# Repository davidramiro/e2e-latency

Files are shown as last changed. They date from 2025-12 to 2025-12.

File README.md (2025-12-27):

# m2p-latency

Get a rough estimate on mouse-to-photon (time until a mouse input triggers a screen change) system latency by attaching a phototransistor to your screen and measuring response time with an Arduino.

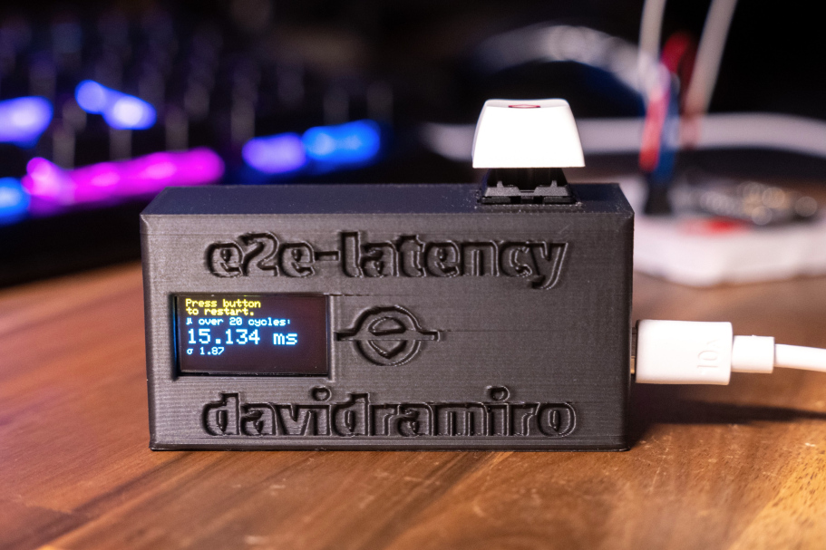
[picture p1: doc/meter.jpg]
Latency Meter


## BoM

- Arduino Pro Micro (ATmega32U4)
- SSD1306 I2C OLED screen
- TEMT6000 phototransistor
- Cherry MX switch

## Wiring

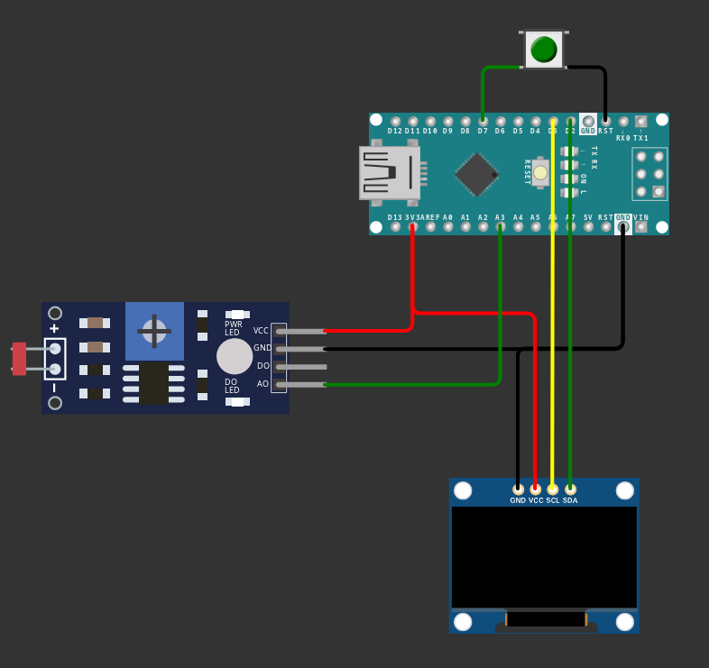
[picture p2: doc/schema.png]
Wiring


## Usage

- Set up a repeatable test scenario where a mouse click would cause a screen change (e.g. FPS game, mouse latency test at [testufo.com](https://testufo.com/flicker)
- Hold the photo transistor to the screen
- Connect USB
- Press button to start 20 measurements, wait for average to be reported on screen

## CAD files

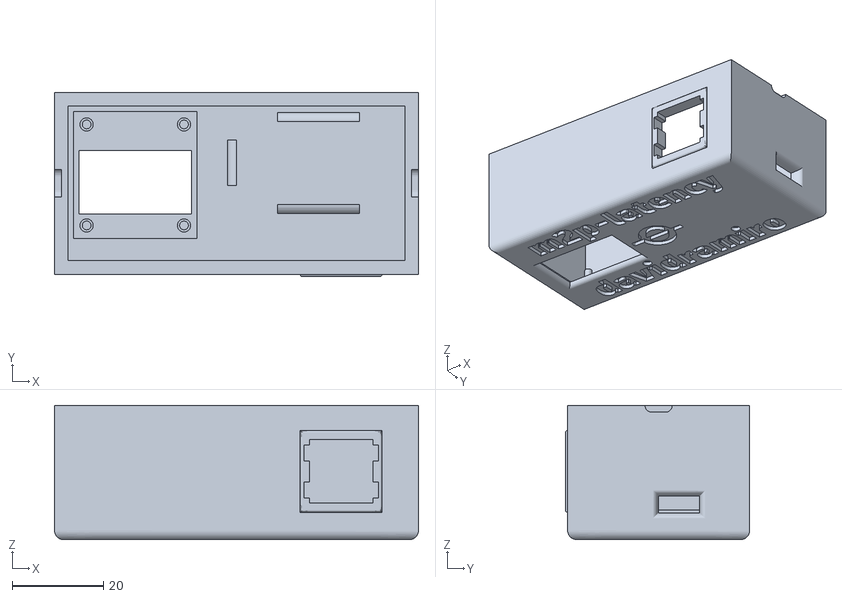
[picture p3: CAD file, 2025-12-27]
case/case.stl
80.0 x 40.5 x 29.5

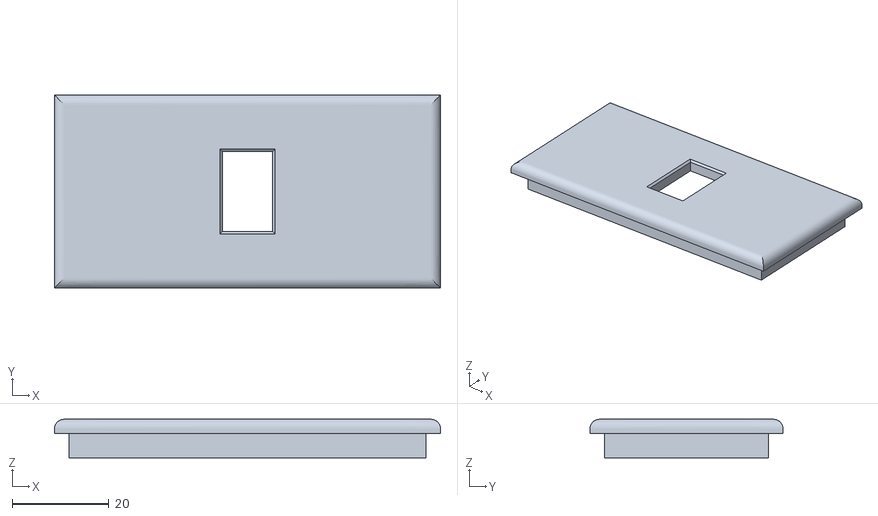
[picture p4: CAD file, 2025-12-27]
case/lid.stl
80.0 x 40.0 x 8.00

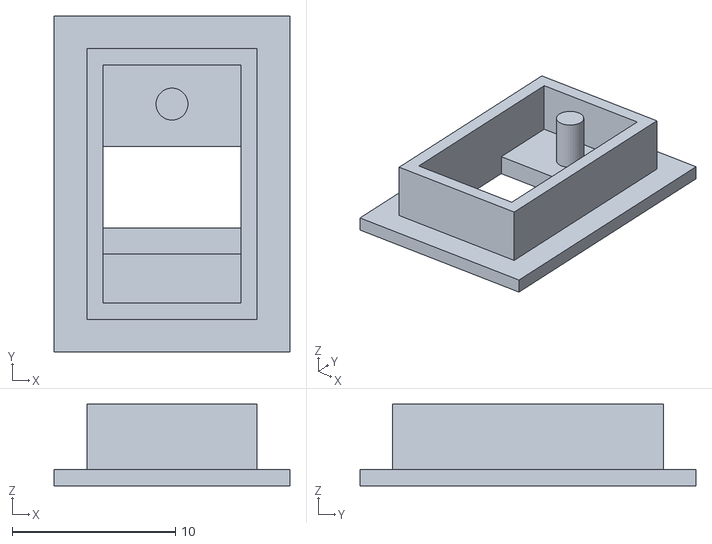
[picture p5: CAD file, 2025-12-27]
case/housing.stl
14.5 x 20.6 x 5.00

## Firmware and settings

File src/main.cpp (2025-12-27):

#include "main.h"

uint32_t latencies_us[NUM_CYCLES] = {0};
uint8_t cycle_index = 0;

volatile boolean startRequested = false;
volatile boolean restartRequested = false;
boolean running = false;

/// @brief Inits analog pin and mouse HID
void setup()
{
  initScreen();

  pinMode(BUTTON_PIN, INPUT_PULLUP);
  attachInterrupt(digitalPinToInterrupt(BUTTON_PIN), isr, FALLING);
}

/// @brief Measures brightness, waits for brightness change, saves latency. Shows an average after last cycle.
void loop()
{
  if (startRequested)
  {
    startRequested = false;
    restartRequested = false;
    Mouse.begin();

    while (cycle_index < NUM_CYCLES)
    {
      measure();

      if (restartRequested)
      {
        Mouse.release();
        cycle_index = 0;

        drawInterrupted();
        delay(1000);
        startRequested = false;
        restartRequested = false;
        running = false;
        drawStartupScreen();
        break;
      }
    }

    if (cycle_index == NUM_CYCLES)
    {

      double mean_ms = 0.0;
      double sd_ms = 0.0;
      computeStatsMs(&mean_ms, &sd_ms);
      printAverage(mean_ms, sd_ms);

      cycle_index = 0;
      running = false;
      startRequested = false;
      restartRequested = false;
      Mouse.end();
    }
  }
}

void measure()
{
  // get reference brightness
  uint16_t baseline = analogRead(SENSOR_PIN);
  printMeasurement(baseline, cycle_index, 0.0);

  delay(MEASUREMENT_DELAY_MS);

  running = true;

  baseline = analogRead(SENSOR_PIN);

  // reset timer, click mouse
  const unsigned long start = micros();
  Mouse.press(MOUSE_LEFT);

  while (true)
  {
    if (restartRequested)
    {
      return;
    }

    const int delta = analogRead(SENSOR_PIN) - baseline;

    // loop until brightness delta is bigger than threshold
    if (abs(delta) > BRIGHTNESS_THRESHOLD)
    {
      // save and sum measured latency
      long latency = micros() - start - internalLatency;
      Mouse.release();

      if (latency <= 0)
      {
        printError();
        delay(1000);
        break;
      }

      // store cycle in the array
      if (cycle_index < NUM_CYCLES)
      {
        latencies_us[cycle_index] = latency;
      }

      printMeasurement(baseline, cycle_index, latency / MS_FACTOR, baseline + delta);

      delay(MEASUREMENT_DELAY_MS);

      cycle_index++;
      break;
    }
  }
}

void isr()
{
  if (running)
  {
    restartRequested = true;
  }
  else
  {
    startRequested = true;
  }
}

/// @brief Calculates mean latency and sample standard deviation for an array of us latencies.
void computeStatsMs(double *mean_ms, double *sd_ms)
{
  double sum_us = 0.0;
  double sd_us = 0.0;
  double mean_us = 0.0;
  double variance_us = 0.0;

  if (NUM_CYCLES == 0)
  {
    *mean_ms = 0.0;
    *sd_ms = 0.0;
    return;
  }

  if (NUM_CYCLES == 1)
  {
    *mean_ms = (double)latencies_us[0] / MS_FACTOR;
    *sd_ms = 0.0;
    return;
  }

  // calculate mean
  for (int i = 0; i < NUM_CYCLES; i++)
  {
    sum_us += (double)latencies_us[i];
  }
  mean_us = sum_us / (double)NUM_CYCLES;

  // calculate sample standard deviation

  for (int i = 0; i < NUM_CYCLES; i++)
  {
    const double diff_us = ((double)latencies_us[i]) - mean_us;
    variance_us += diff_us * diff_us;
  }
  sd_us = sqrt(variance_us / (NUM_CYCLES - 1));

  *mean_ms = mean_us / MS_FACTOR;
  *sd_ms = sd_us / MS_FACTOR;
}

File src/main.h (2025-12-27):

#pragma once

#include <Arduino.h>
#include "Mouse.h"
#include <math.h>
#include "display.h"

/// @brief Analog pin connected to signal of photodiode/photoresistor
static const uint8_t SENSOR_PIN = A3;
/// @brief Pin shorted to ground via button
static const uint8_t BUTTON_PIN = 7;
/// @brief RX LED PIN to show fault
static const uint8_t RX_LED_PIN = 17;
/// @brief Sensor threshold for registering a screen change event in 40 mV increments of the analog readout.
static const uint16_t BRIGHTNESS_THRESHOLD = 10;
/// @brief Number of measurements before calculating summary
static const uint8_t NUM_CYCLES = 20;
/// @brief Internal latency of the analog read, this lag will be subtracted from the measured latency
static const uint16_t internalLatency = 112;

static const uint16_t MEASUREMENT_DELAY_MS = 287;
static const double MS_FACTOR = 1000.0;

void initScreen();
void isr();
void measure();
void computeStatsMs(double *mean_ms, double *sd_ms);

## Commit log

2024-03-11 feat: add i2c screen
2025-12-15 refactor: use micros instead of chrono for tighter timing, click instead of move
    [main.cpp, main.h]
2025-12-16 feat: blink rx led on display error
    [main.cpp]
2025-12-17 feat: wait for button press to start
2025-12-18 feat: wait for button after cycle
2025-12-19 feat: subtract ADC latency
2025-12-19 fix: remove unused lib
    [main.h]
2025-12-21 doc: add button to schematic
2025-12-21 fix: use absolute threshold for change detection
    [main.cpp]
2025-12-22 feat: add restarting interrupt
2025-12-24 doc: update schematic
2025-12-27 refactor: remove busy wait for button
2025-12-27 chore: add case STLs
    [case.stl, housing.stl, lid.stl]
